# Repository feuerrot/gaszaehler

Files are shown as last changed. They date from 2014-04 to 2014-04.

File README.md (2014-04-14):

# Gaszählersensor

Dieses Projekt dient dazu, einen über Doppelader angeschlossenen Sensor am
Gaszähler an einen S0-Eingang anzubinden

Der Gaszähler hat in der 6 der dritten Nachkommarstelle eine reflektierende
Scheibe, was es ermöglicht, den Gasverbrauch auf jeweils 1L genau zu
messen.

Da bis zum Gaszähler nur eine Doppelader liegt, schaltet der CNY-70 über
einen Vorwiderstand einen Transistor, wodurch mehr Strom verbraucht wird.
Diese Stromdifferenz wird am anderen Ende der Doppelader dann in ein
binäres Signal übertragen und steht über einen Optokoppler potentialfrei
zur Verfügung.

## Schaltplan

### Sensor
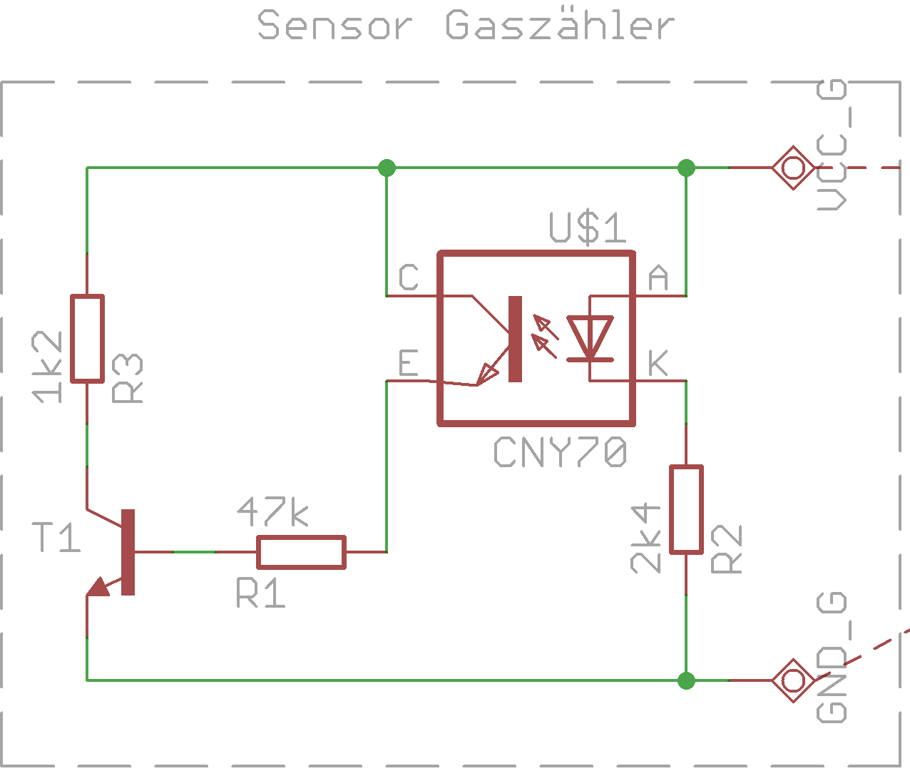
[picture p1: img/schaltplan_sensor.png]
Schaltplan des Sensors am Gaszähler


### Konverter
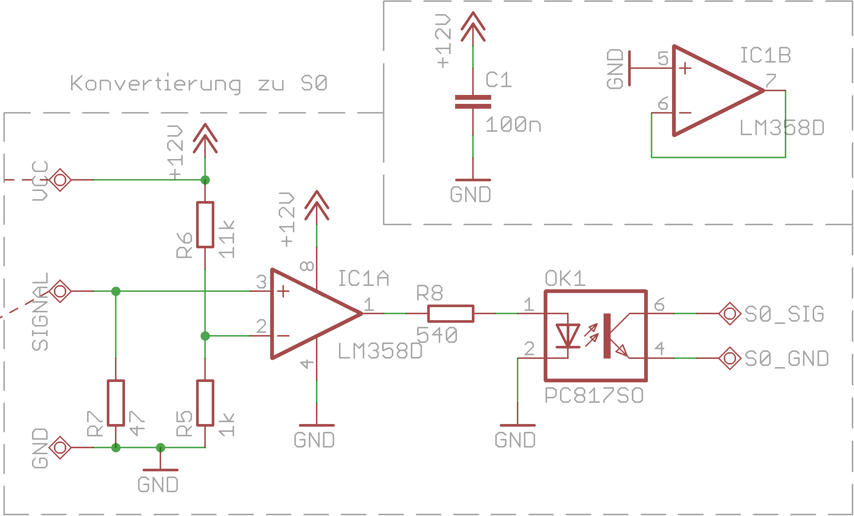
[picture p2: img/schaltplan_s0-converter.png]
Schaltplan des Konverters


### Beides
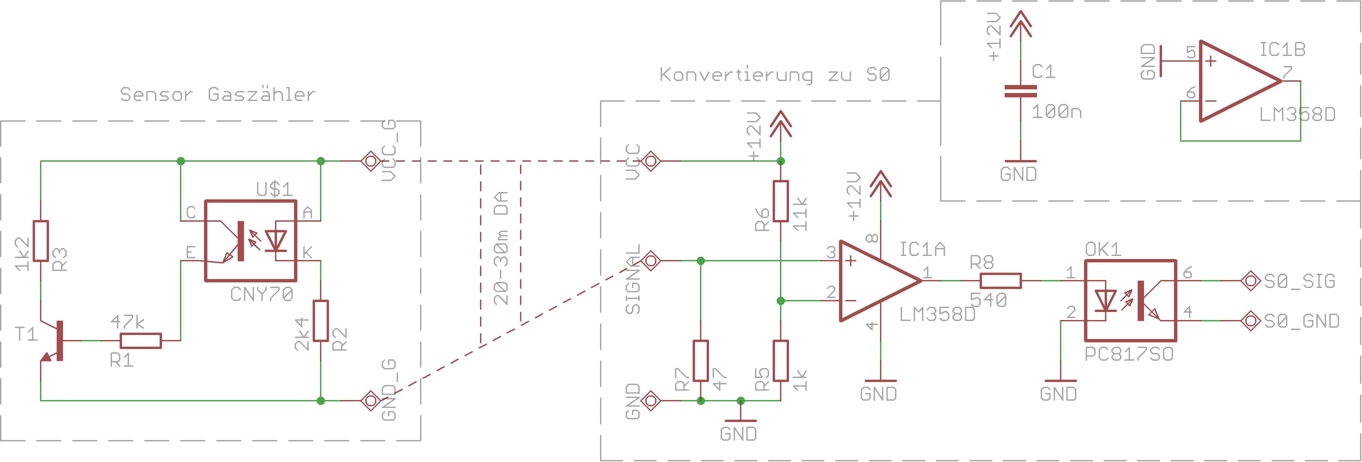
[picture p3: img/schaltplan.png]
Komplettschaltplan


## Layout

### Sensor
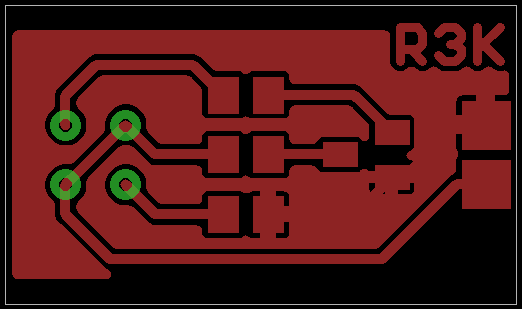
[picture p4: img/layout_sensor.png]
Layout des Sensors am Gaszähler


### Konverter
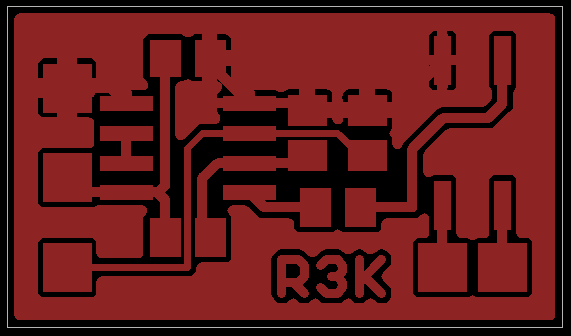
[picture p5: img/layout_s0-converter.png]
Layout des Konverters


### Beides
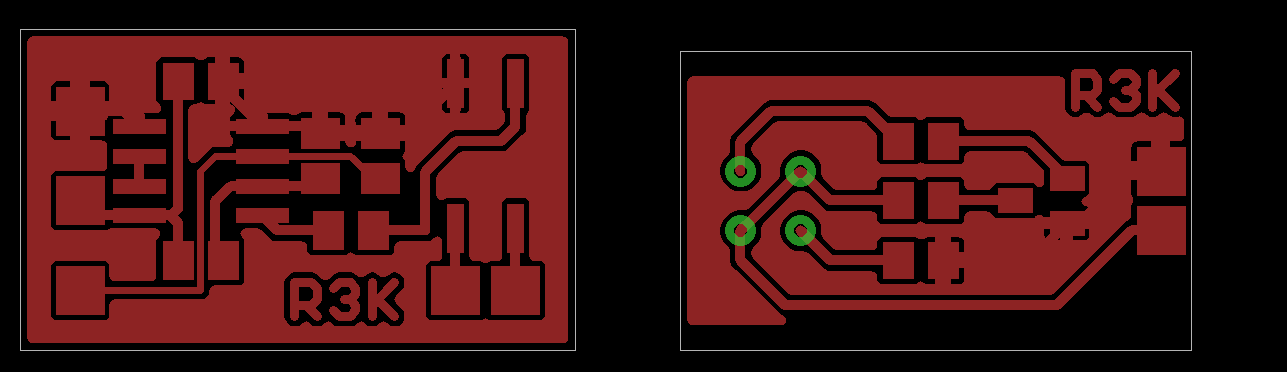
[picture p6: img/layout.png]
Komplettlayout


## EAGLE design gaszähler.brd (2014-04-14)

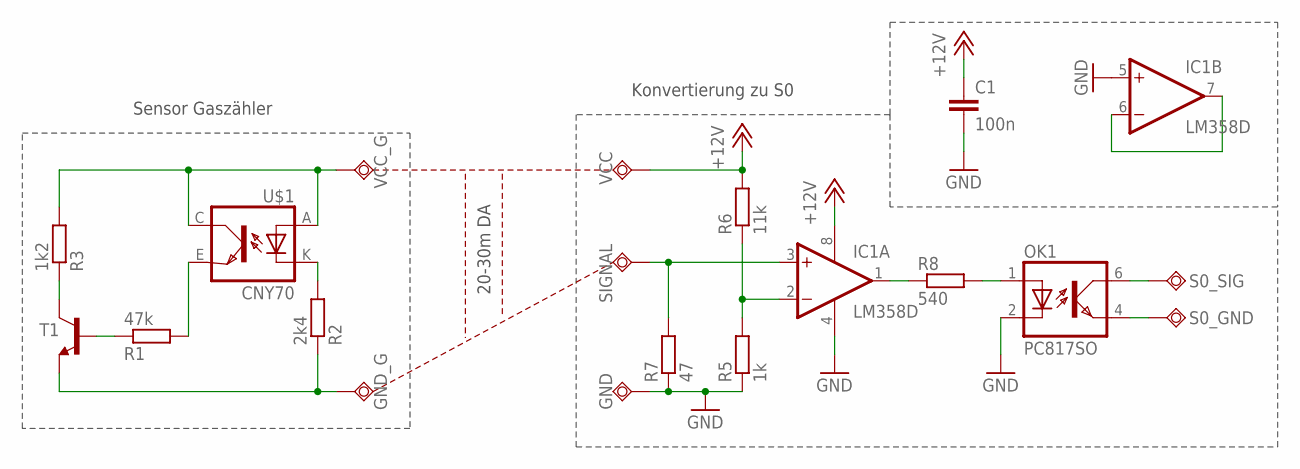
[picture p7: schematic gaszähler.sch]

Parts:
C1: 100n; C0805
GND: TPSQTP20SQ; TP20SQ
GND_G: TPSQTP20SQ; TP20SQ
IC1: LM358D; SO08
OK1: PC817SO; SO4
R1: 47k; R0805
R2: 2k4; R0805
R3: 1k2; R0805
R5: 1k; M0805
R6: 11k; M0805
R7: 47; M0805
R8: 540; M0805
S0_GND, S0_SIG: TPSQTP20SQ; TP20SQ
SIGNAL: TPSQTP20SQ; TP20SQ
T1: -NPN-SOT23-EBC; SOT23-EBC
U$1: CNY70; 4
VCC: TPSQTP20SQ; TP20SQ
VCC_G: TPSQTP20SQ; TP20SQ

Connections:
+12V: C1.1, IC1.8 (V+), R6.2, VCC.TP
GND: C1.2, GND.TP, IC1.4 (V-), IC1.5 (+IN), OK1.2 (C), R5.1, R7.1
GND_G: GND_G.TP, R2.1, T1.E
unnamed: IC1.2 (-IN), R5.2, R6.1
unnamed: R2.2, U$1.K (C)
unnamed: R1.2, U$1.E (EMI)
unnamed: IC1.3 (+IN), R7.2, SIGNAL.TP
unnamed: R1.1, T1.B
unnamed: R3.1, T1.C
unnamed: OK1.6 (COL), S0_SIG.TP
unnamed: IC1.1 (OUT), R8.1
unnamed: OK1.4 (EMIT), S0_GND.TP
unnamed: OK1.1 (A), R8.2
unnamed: IC1.6 (-IN), IC1.7 (OUT)
unnamed: R3.2, U$1.A, U$1.C (COL), VCC_G.TP

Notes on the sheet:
20-30m DA
Sensor Gaszähler
Konvertierung zu S0

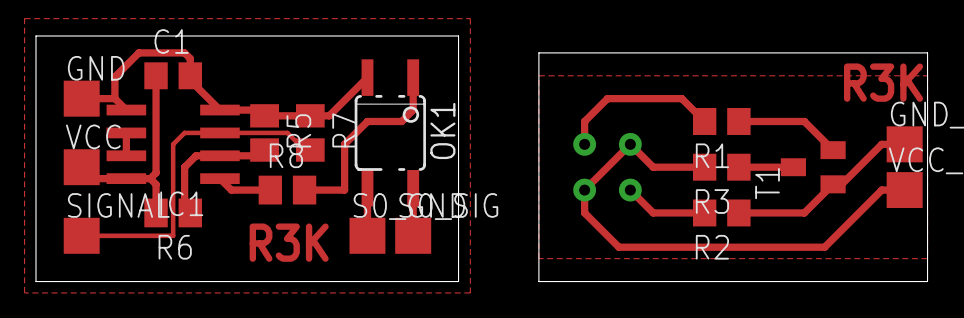
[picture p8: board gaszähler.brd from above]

Board: 2 copper layers, 49.5 x 13.6 mm, 19 parts (1 on the bottom side), 15 nets.

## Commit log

2014-04-14 adding images
    [gaszähler.brd, gaszähler.sch]
2014-04-14 Readme + Bilder der zwei Teile
2014-04-14 Beschreibung umformuliert und Bilder den kompletten Schaltplan hinzugefügt
